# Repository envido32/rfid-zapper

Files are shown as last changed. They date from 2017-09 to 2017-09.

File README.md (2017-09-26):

# RFID Zapper

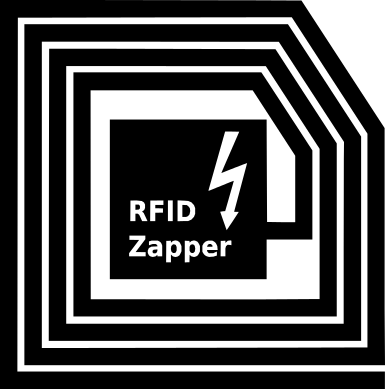
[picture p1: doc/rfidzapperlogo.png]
RFID Zapper


RFID Zapper sirve para quemar, dejando fuera de funcionamiento de forma irreversible los chips tipo RFID como el que se encuentran en llaves de puertas electronicas, [tarjetas de transporte público](https://www.sube.gob.ar/), [pasaportes](https://www.digitalcourage.de/), [boletas de voto electrónico](https://youtu.be/bJT6KLP6tWA), etc. No deja marca visible en absoluto ni emite ruido alguno. 

Este dispositivo debe utilizarse SOLO con fines didácticos o de pruebas. El mal uso del mismo **puede ocasionar serios daños en dispositivos electrónicos.**

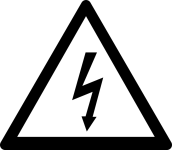
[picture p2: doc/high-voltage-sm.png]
Alto Voltaje


**ATENCIÓN! Este dispositivo tiene una salida en ALTO VOLTAJE. Puede ocasionar daños en el organismo o incluso la muerte si se aplica la descarga sobre el cuerpo. Debe manipularse adecuadamente. No utilizar sin protección adecuada.**

## Licencia

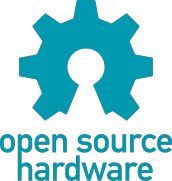
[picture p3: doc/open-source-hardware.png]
Open Source Hardware
 

RFID Zapper es un proyecto libre realizado por [*Manolo Envido*](https://twitter.com/Envido32), basado en el diseño presentado en la serie de videos de [*The Post Apocalyptic Inventor*](https://www.youtube.com/watch?v=E_Nsf0uU8IY&list=PLxaGnte1Dq0my2dtPL5y8sPR7xYXRrOCb).

Libre para utilizar, modificar, compartir y demás bajo los términos de la licencia [CERN Open Hardware Licence v1.2](LICENSE).

## Principio de funcionamiento

Se trata de un circuito elevador de tensión alimentado por una batería alcalina de 9v. Este elevador carga el capacitor y luego al cerrar el segundo interruptor se descarga el capacitor a través de la antena RFID. Esto genera un pulso electromagnético que al ser captado por un chip RFID lo utilizara como alimentación. Al ser un pulso de alta intensidad (y corta duración) la energía absorbida por el chip sera más alta que la soportada por el integrado probocándole un daño irreparable de forma totalmente silenciosa e invisible.

El circuito elevador de tensión es del tipo [boost](https://en.wikipedia.org/wiki/Boost_converter) alimentado por una [batería alcalina de 9v](https://en.wikipedia.org/wiki/Nine-volt_battery). Este circuito es controlado por un [PWM](https://en.wikipedia.org/wiki/Pulse-width_modulation) básico realizado con el [Timer 555](https://en.wikipedia.org/wiki/555_timer_IC) y controlado por el potenciómetro, se recomienda evitar un ciclo de trabajo del PWM mayor al 50% para evitar daños a la batería. Una vez cargado el capacitor el circuito de feedback enciende el LED y desactiva el Timer 555.

## Lite Edition

Menos componentes, más compacto. 

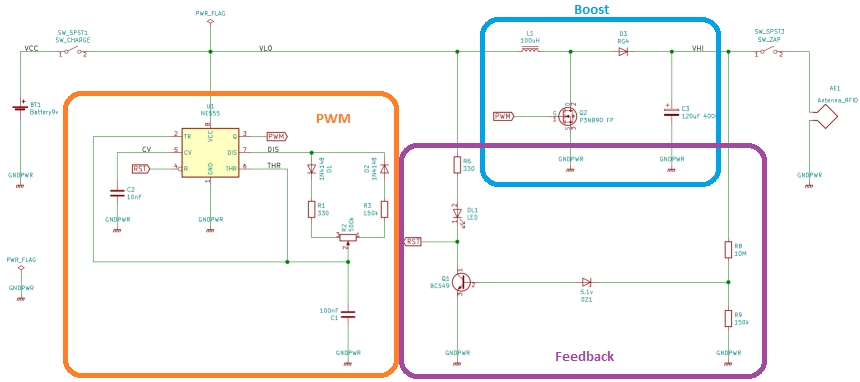
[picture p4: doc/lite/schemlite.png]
Esquema eléctrico


***Made with KiCAD***

Made with KiCAD (http://kicad-pcb.org/)

***Order in PCBWay***

Order in PCBWay (https://www.pcbway.com/project/shareproject/RFID_Zapper.html)

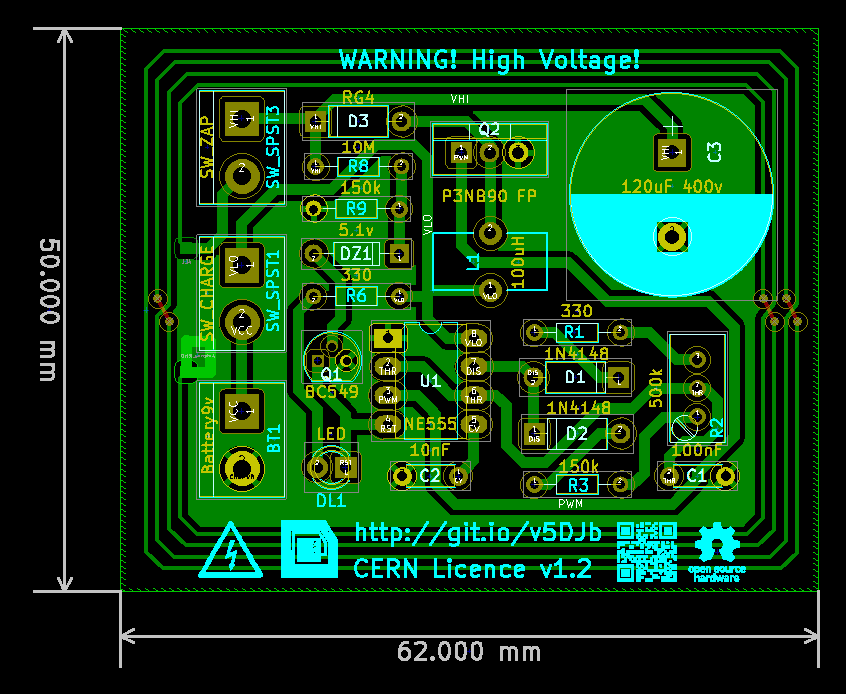
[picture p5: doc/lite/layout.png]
PCB


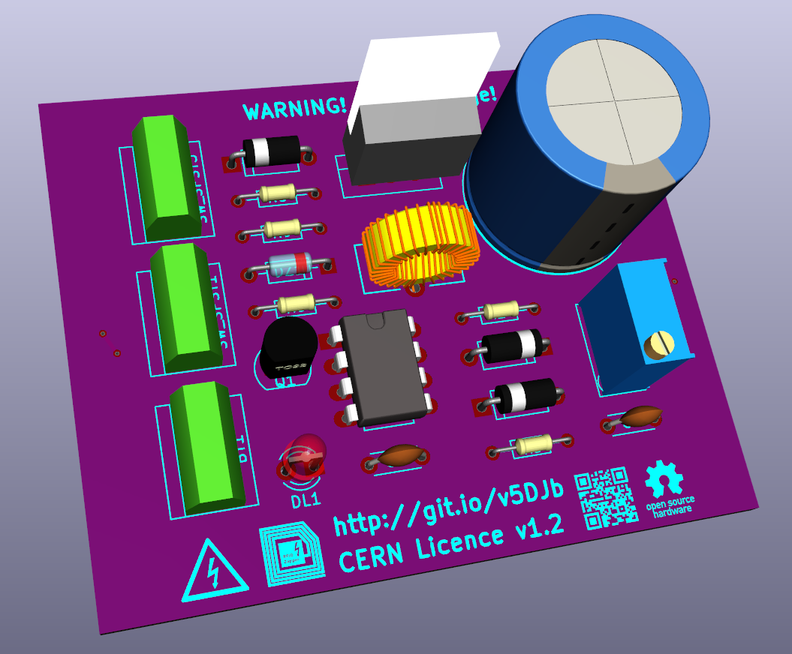
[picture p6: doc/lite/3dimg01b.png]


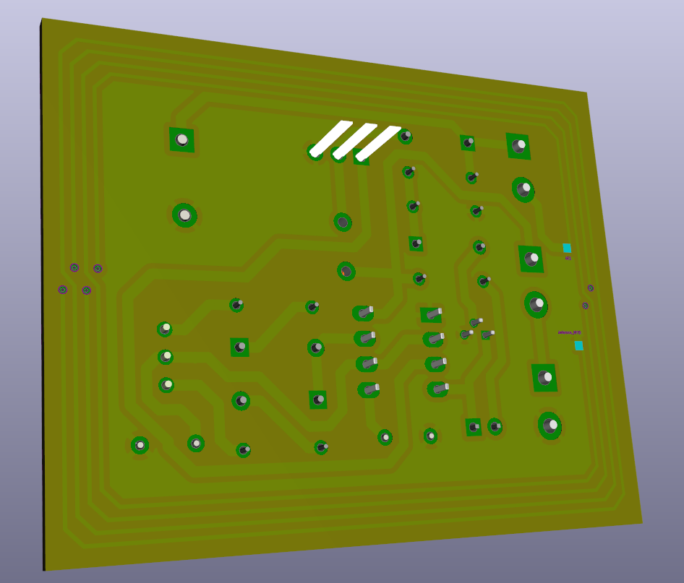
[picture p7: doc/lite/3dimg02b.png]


## Lista de materiales

Description | Part | References | Value | Footprint | Quantity Per PCB
---- | ---- | ---- | ---- | ---- | ---- 
Bornier | 2x1 | SW_SPST1 SW_SPST2 BT1 | SW_CHARGE SW_ZAP Baterry9v | Bornier | 3
Switch | DPDT | SW_SPST1 SW_SPST2 | SW_CHARGE SW_ZAP | Bornier | 1
Battery Cell | Baterry9v | BT1 | Alkaline 9v | Bornier | 1
Timer 555 IC | NE555 | U1 | NE555 | DIP 8 W7.62mm | 1
Capacitor | Ceramic | C1 | 100nF | Disc 4.3mm W1.9mm P5.00mm | 1
Capacitor | Ceramic | C2 | 10nF | Disc 4.3mm W1.9mm P5.00mm | 1
Capacitor | Polarised | C3 | 120uF 400v | Radial D18.0mm P7.50mm | 1
LED | Generic | DL1 | Any colour | LED 3.0mm | 1
Diode | Ultra Fast Recovery Rectifier | D3 | RG4 | P10.16mm | 1
Diode | Generic | D1 D2 | 1N4148 | P10.16mm | 2
Diode | Zenner v5.1 | DZ1 | 1N4733A | P10.16mm | 1
PowerMESH MOSFET | N-CHANNEL 900V 4ohm 3.5 A | Q2 | P3NB90 FP IRF3205| TO-220 | 1
Inductor | With Iron Core | L1 | 100uH | Toroid 5x10mm | 1
Small Signal Transistor | NPN 45V Vce 0.1A Ic | Q1 | BC549 | TO-92 | 1
Resistor | Generic | R1 R6 | 330ohm 1/8w | L3.6mm D1.6mm P7.62mm | 2
Resistor | Generic | R3 R9 | 150kohm 1/8w | L3.6mm D1.6mm P7.62mm | 2
Resistor | Generic | R8 | 10Mohm 1/8w | L3.6mm D1.6mm P7.62mm | 1
Potentionmeter | Trimmer | R2 | 500kohm 1/8w | POT | 1

Costo de los materiales total aproximado (a Septiembre 2017, argentina): 
*10 U$D*

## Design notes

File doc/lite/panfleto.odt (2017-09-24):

PCB visualización

[1] https://www.sube.gob.ar/

[2] https://www.digitalcourage.de/

[3] https://noalvotoelectronico.com/

[4] https://twitter.com/Envido32

[5] https://youtu.be/E_Nsf0uU8IY

[6] https://www.ohwr.org/documents/294

[7] https://en.wikipedia.org/wiki/Boost_converter

[8] https://en.wikipedia.org/wiki/Nine-volt_battery

[9] https://en.wikipedia.org/wiki/Pulse-width_modulation

[10] https://en.wikipedia.org/wiki/555_timer_IC

¡A (https://github.com/envido32/rfid-zapper/blob/master/doc/high-voltage-sm.png)TENCIÓN!

Este dispositivo tiene una salida en ALTO VOLTAJE. Puede ocasionar daños en el organismo o incluso la muerte si se aplica la descarga sobre el cuerpo. Debe manipularse adecuadamente. No utilizar sin protección adecuada.

# RFID Zapper

RFID Zapper

RFID Zapper sirve para quemar, dejando fuera de funcionamiento de forma irreversible los chips tipo RFID como el que se encuentran en llaves de puertas electrónicas, tarjetas de transporte público (https://www.sube.gob.ar/) [1], pasaportes (https://www.digitalcourage.de/) [2], boletas de voto electrónico (https://youtu.be/bJT6KLP6tWA) [3], etc. No deja marca visible en absoluto ni emite ruido alguno.

Este dispositivo debe utilizarse SOLO con fines didácticos o de pruebas. El mal uso del mismo puede ocasionar serios daños en dispositivos electrónicos.

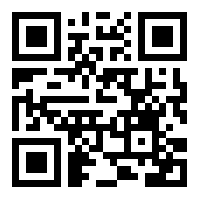
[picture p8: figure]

http://git.io/v5DJb

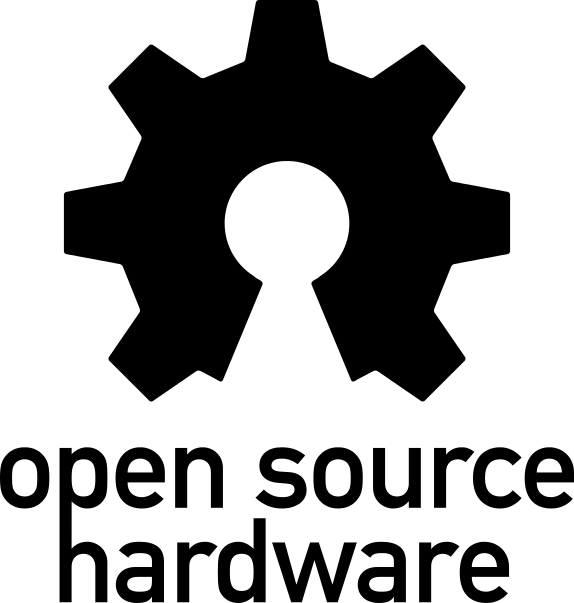
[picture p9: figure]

Licencia

RFID Zapper es un proyecto libre realizado por Manolo Envido (https://twitter.com/Envido32) [4], basado en el diseño presentado en la serie de videos de The Post Apocalyptic Inventor (https://www.youtube.com/watch?v=E_Nsf0uU8IY&list=PLxaGnte1Dq0my2dtPL5y8sPR7xYXRrOCb) [5].

Libre para utilizar, modificar, compartir y demás bajo los términos de la licencia CERN Open Hardware Licence v1.2 (https://github.com/envido32/rfid-zapper/blob/master/LICENSE) [6].

## Principio de funcionamiento

Se trata de un circuito elevador de tensión alimentado por una batería alcalina de 9v. Este elevador carga el capacitor y luego al cerrar el segundo interruptor se descarga el capacitor a través de la antena RFID. Esto genera un pulso electromagnético que al ser captado por un chip RFID lo utilizara como alimentación. Al ser un pulso de alta intensidad (y corta duración) la energía absorbida por el chip sera más alta que la soportada por el integrado probocándole un daño irreparable de forma totalmente silenciosa e invisible.

Esquema eléctrico

(https://github.com/envido32/rfid-zapper/blob/master/doc/lite/schemlite.png)

El circuito elevador de tensión es del tipo boost (https://en.wikipedia.org/wiki/Boost_converter) [7] alimentado por una batería alcalina de 9v (https://en.wikipedia.org/wiki/Nine-volt_battery) [8]. Este circuito es controlado por un PWM (https://en.wikipedia.org/wiki/Pulse-width_modulation) [9] básico realizado con el Timer 555 (https://en.wikipedia.org/wiki/555_timer_IC) [10] y controlado por el potenciómetro, se recomienda evitar un ciclo de trabajo del PWM mayor al 50% para evitar daños a la batería. Una vez cargado el capacitor el circuito de feedback enciende el LED y desactiva el Timer 555.

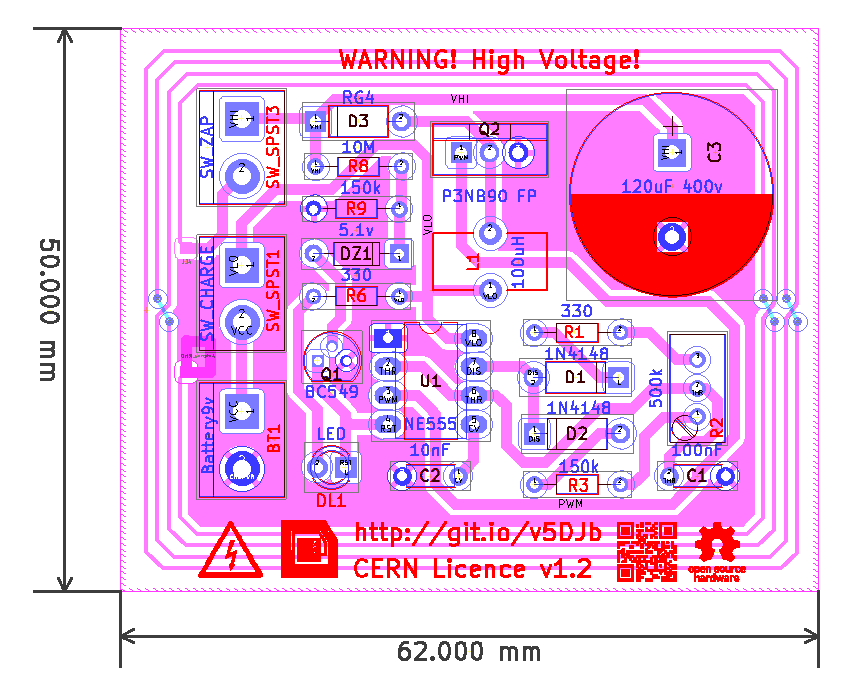
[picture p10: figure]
PCB

(https://github.com/envido32/rfid-zapper/blob/master/doc/lite/layout.png)

## Lista de materiales

Description | Part | References | Value | Footprint | Quantity Per PCB
Bornier | 2x1 | SW_SPST1 SW_SPST2 BT1 | SW_CHARGE SW_ZAP Baterry9v | Bornier | 3
Switch | DPDT | SW_SPST1 SW_SPST2 | SW_CHARGE SW_ZAP | Bornier | 1
Battery Cell | Baterry9v | BT1 | Alkaline 9v | Bornier | 1
Timer 555 IC | NE555 | U1 | NE555 | DIP 8 W7.62mm | 1
Capacitor | Ceramic | C1 | 100nF | Disc 4.3mm W1.9mm P5.00mm | 1
Capacitor | Ceramic | C2 | 10nF | Disc 4.3mm W1.9mm P5.00mm | 1
Capacitor | Polarised | C3 | 120uF 400v | Radial D18.0mm P7.50mm | 1
LED | Generic | DL1 | Any colour | LED 3.0mm | 1
Diode | Ultra Fast Recovery Rectifier | D3 | RG4 | P10.16mm | 1
Diode | Generic | D1 D2 | 1N4148 | P10.16mm | 2
Diode | Zenner v5.1 | DZ1 | 1N4733A | P10.16mm | 1
PowerMESH MOSFET | N-CHANNEL 900V 4ohm 3.5 A | Q2 | P3NB90 FP IRF3205 | TO-220 | 1
Inductor | With Iron Core | L1 | 100uH | Toroid 5x10mm | 1
Small Signal Transistor | NPN 45V Vce 0.1A Ic | Q1 | BC549 | TO-92 | 1
Resistor | Generic | R1 R6 | 330ohm 1/8w | L3.6mm D1.6mm P7.62mm | 2
Resistor | Generic | R3 R9 | 150kohm 1/8w | L3.6mm D1.6mm P7.62mm | 2
Resistor | Generic | R8 | 10Mohm 1/8w | L3.6mm D1.6mm P7.62mm | 1
Potentionmeter | Trimmer | R2 | 500kohm 1/8w | POT | 1

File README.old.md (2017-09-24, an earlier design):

# RFID Zapper

RFID Zapper

RFID Zapper sirve para quemar, dejando fuera de funcionamiento de forma irreversible los chips tipo RFID como el que se encuentran en llaves de puertas electronicas, [tarjetas de transporte público](https://www.sube.gob.ar/), [pasaportes](https://www.digitalcourage.de/), [boletas de voto electrónico](https://youtu.be/bJT6KLP6tWA), etc. No deja marca visible en absoluto ni emite ruido alguno. 

Este dispositivo debe utilizarse SOLO con fines didácticos o de pruebas. El mal uso del mismo **puede ocasionar serios daños en dispositivos electrónicos.**

Alto Voltaje

**ATENCIÓN! Este dispositivo tiene una salida en ALTO VOLTAJE. Puede ocasionar daños en el organismo o incluso la muerte si se aplica la descarga sobre el cuerpo. Debe manipularse adecuadamente. No utilizar sin protección adecuada.**

## Licencia

Open Source Hardware

RFID Zapper es un proyecto libre realizado por [*Manolo Envido*](https://twitter.com/Envido32), basado en el diseño presentado en la serie de videos de [*The Post Apocalyptic Inventor*](https://www.youtube.com/watch?v=E_Nsf0uU8IY&list=PLxaGnte1Dq0my2dtPL5y8sPR7xYXRrOCb)

Libre para utilizar, modificar, compartir y demás bajo los términos de la licencia [CERN Open Hardware Licence v1.2](LICENSE).

## Principio de funcionamiento

Se trata de un circuito elevador de tensión alimentado por una batería alcalina de 9v. Este elevador carga el capacitor y luego al cerrar el segundo interruptor se descarga el capacitor a través de la antena RFID. Esto genera un pulso electromagnético que al ser captado por un chip RFID lo utilizara como alimentación. Al ser un pulso de alta intensidad (y corta duración) la energía absorbida por el chip sera más alta que la soportada por el integrado probocándole un daño irreparable de forma totalmente silenciosa e invisible.

El circuito elevador de tensión es del tipo [boost](https://en.wikipedia.org/wiki/Boost_converter) alimentado por una [batería alcalina de 9v](https://en.wikipedia.org/wiki/Nine-volt_battery). Este circuito es controlado por un [PWM](https://en.wikipedia.org/wiki/Pulse-width_modulation) básico realizado con el [Timer 555](https://en.wikipedia.org/wiki/555_timer_IC) y controlado por el potenciómetro, se recomienda evitar un ciclo de trabajo del PWM mayor al 50% para evitar daños a la batería. Una vez cargado el capacitor el circuito de feedback enciende el LED y desactiva el Timer 555.

## Original Edition

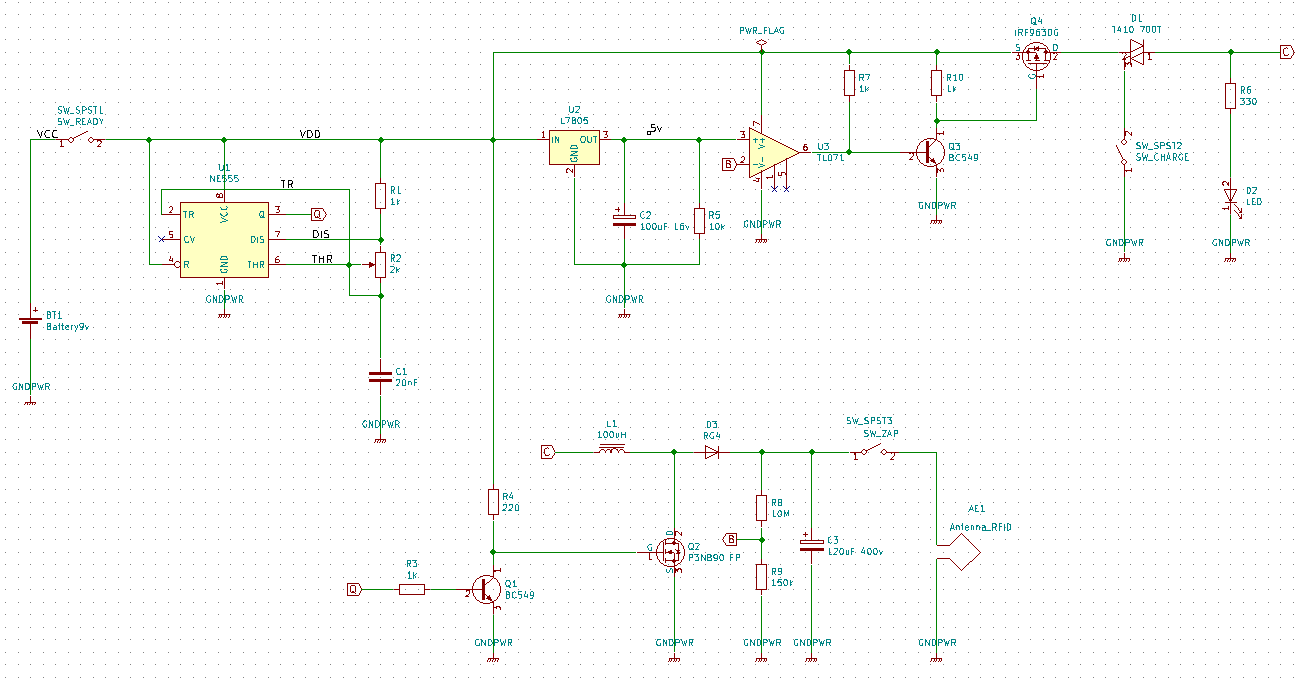
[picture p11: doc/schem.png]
Esquema eléctrico


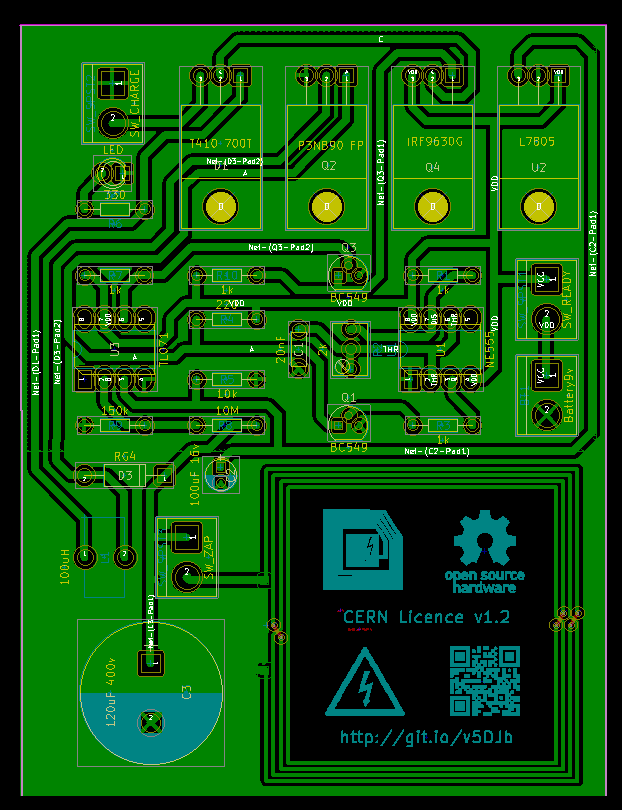
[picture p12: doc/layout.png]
PCB


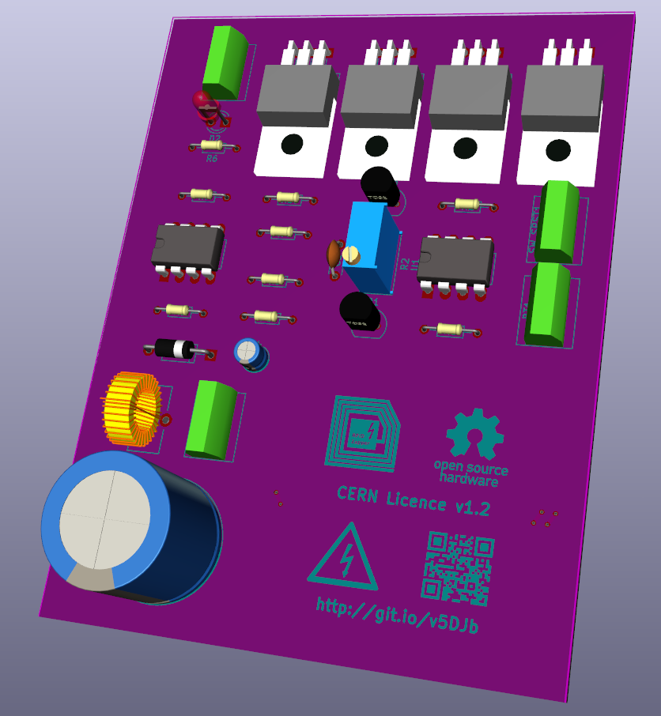
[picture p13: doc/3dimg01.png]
PCB visualización


## Lista de materiales

Description | Part | References | Value | Footprint | Quantity Per PCB
---- | ---- | ---- | ---- | ---- | ---- 
single battery cell | Battery_Cell | BT1 | Battery9v | bornier2 | 1
Polarised capacitor | CP | C2 | 100uF 16v | CP_Radial_D4.0mm_P2.00mm | 1
Polarised capacitor | CP | C3 | 120uF 400v | CP_Radial_D18.0mm_P7.50mm | 1
Unpolarized capacitor | C | C1 | 20nF | C_Disc_D4.3mm_W1.9mm_P5.00mm | 1
LED generic | LED | D2 | LED | LED_D3.0mm | 1
Diode | D | D3 | RG4 | D_A-405_P10.16mm_Horizontal | 1
triode for alternating current (TRIAC) | Q_TRIAC_AAG | D1 | T410 700T | TO-220_Horizontal | 1
Inductor with Iron Core | L_Core_Iron | L1 | 100uH | Choke_Toroid_5x10mm_Vertical | 1
45V Vce, 0.1A Ic, NPN, Small Signal Transistor, TO-92 | BC549 | Q1 Q3 | BC549 | TO-92_Molded_Narrow | 2
6.5A, 200V, 0.800 Ohm, P-Channel Power MOSFET | IRF9540N-RESCUE-RFIDZapper | Q4 | IRF9630G | TO-220_Horizontal | 1
N - CHANNEL 900V - 4 ohm - 3.5 A PowerMESH MOSFET | IRF3205 | Q2 | P3NB90 FP | TO-220_Horizontal | 1
Resistor | R | R8 | 10M | R_Axial_DIN0204_L3.6mm_D1.6mm_P7.62mm_Horizontal | 1
Resistor | R | R5 | 10k | R_Axial_DIN0204_L3.6mm_D1.6mm_P7.62mm_Horizontal | 1
Resistor | R | R9 | 150k | R_Axial_DIN0204_L3.6mm_D1.6mm_P7.62mm_Horizontal | 1
Resistor | R | R1 R3 R7 R10 | 1k | R_Axial_DIN0204_L3.6mm_D1.6mm_P7.62mm_Horizontal | 4
Resistor | R | R4 | 220 | R_Axial_DIN0204_L3.6mm_D1.6mm_P7.62mm_Horizontal | 1
Potentionmeter | POT | R2 | 2k | Potentiometer_Trimmer_Bourns_3266Y | 1
Resistor | R | R6 | 330 | R_Axial_DIN0204_L3.6mm_D1.6mm_P7.62mm_Horizontal | 1
Switch | SW_SPST | SW_SPST2 | SW_CHARGE | bornier2 | 1
Switch | SW_SPST | SW_SPST1 | SW_READY | bornier2 | 1
Switch | SW_SPST | SW_SPST3 | SW_ZAP | bornier2 | 1
5V Voltage regulator | L7805 | U2 | L7805 | TO-220_Horizontal | 1
555-series timer IC | NE555 | U1 | NE555 | DIP-8_W7.62mm_LongPads | 1
Low-Noise JFET-Input Operational Amplifier | TL071-RESCUE-RFIDZapper | U3 | TL071 | DIP-8_W7.62mm_LongPads | 1

Las resistencias son todas de 1/8W o 1/4W. Las llaves/switches y la batería se conectan con borneras o pines. Es recomendable incorporar un pequeño disipador al Q2 (P3NB90).

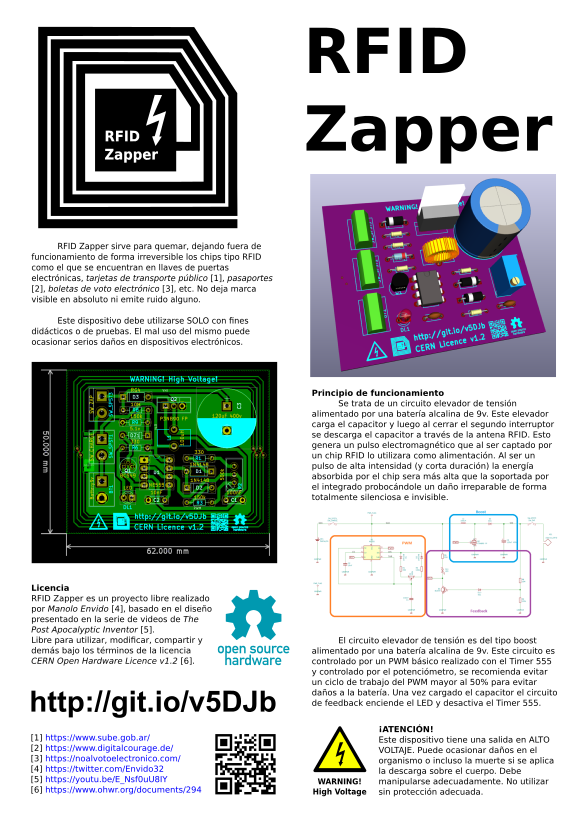
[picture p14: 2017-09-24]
doc/lite/postersm.png

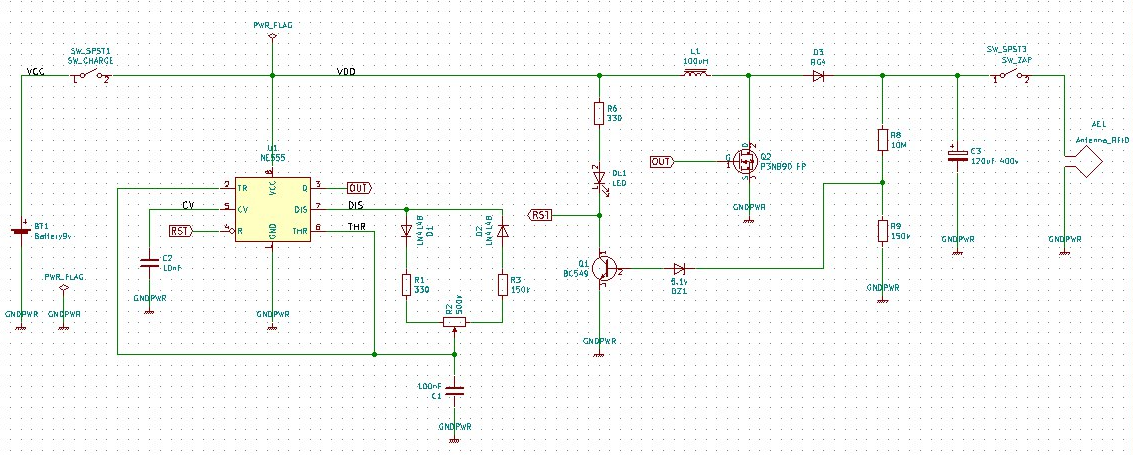
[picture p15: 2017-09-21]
doc/lite/schemlite2.png

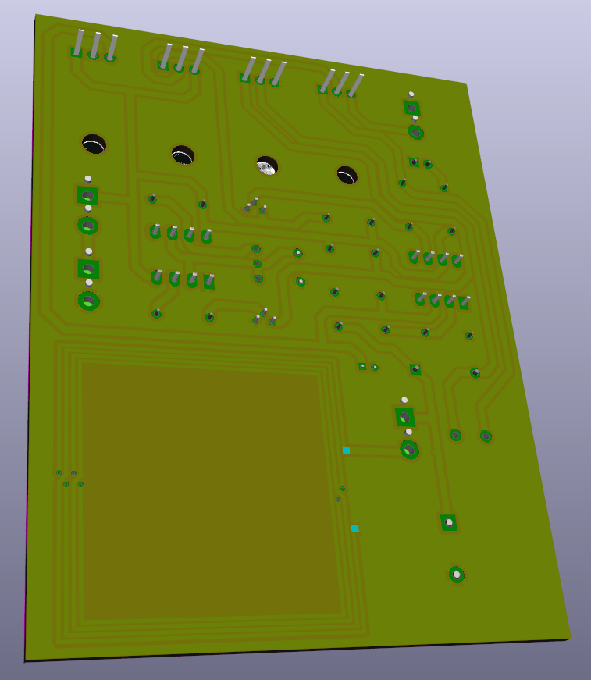
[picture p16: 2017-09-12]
doc/3dimg02.png

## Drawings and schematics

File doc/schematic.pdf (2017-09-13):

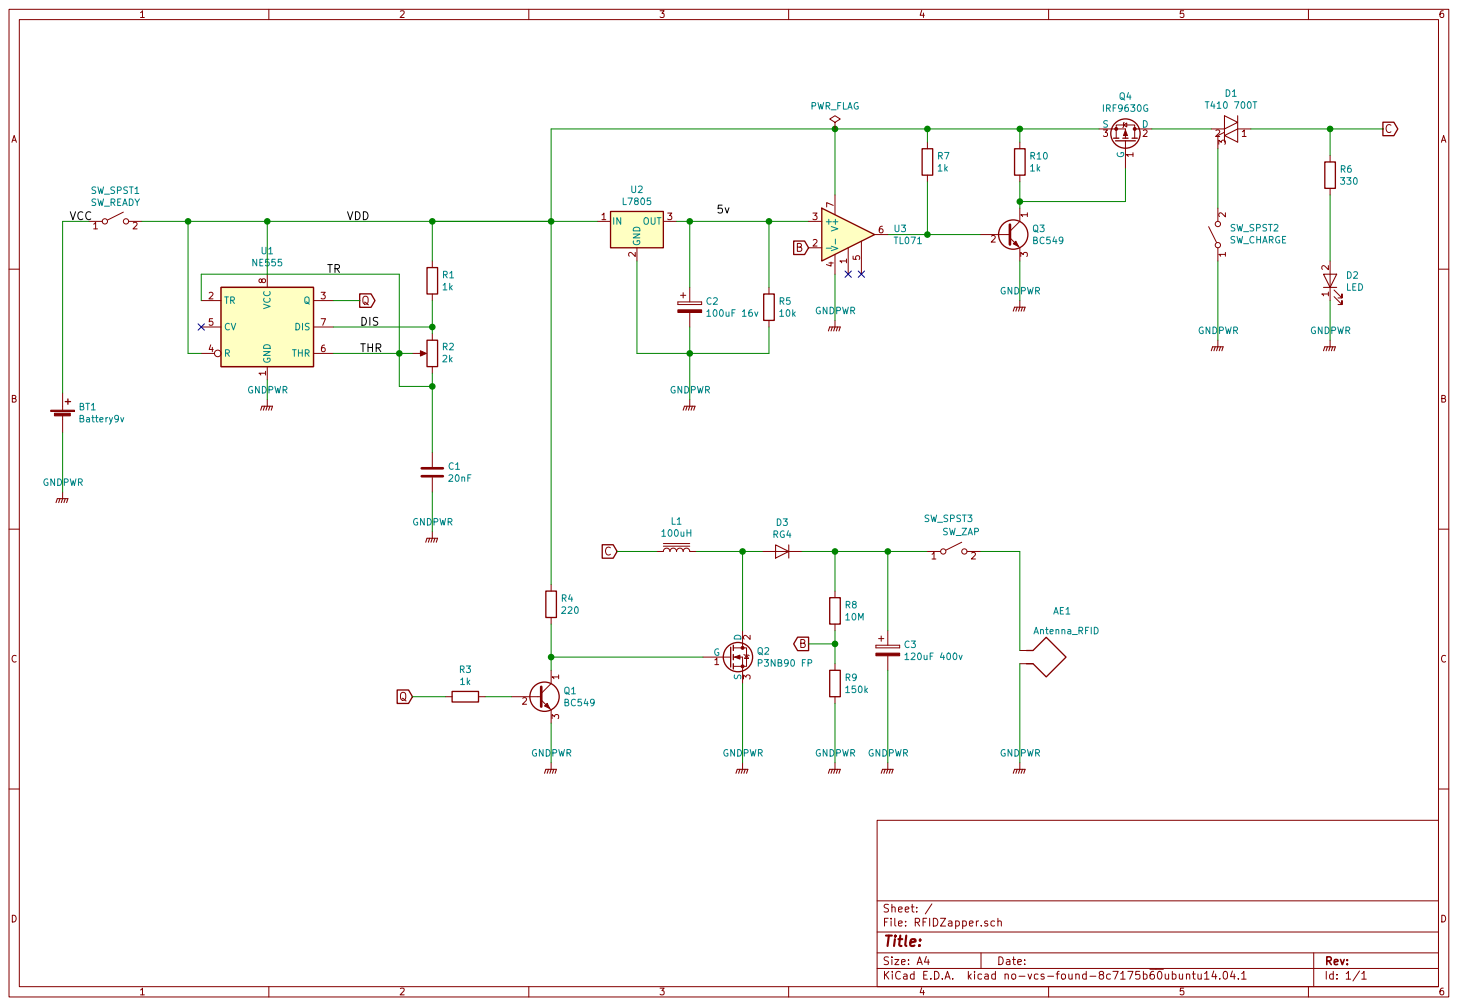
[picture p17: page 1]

3 Q2P3NB90 FP GNDPWR GNDPWR GNDPWR GNDPWR GNDPWR GNDPWR GNDPWR GNDPWR GNDPWR GNDPWR

File: RFIDZapper.sch Sheet: /
Id: 1/1 Title:

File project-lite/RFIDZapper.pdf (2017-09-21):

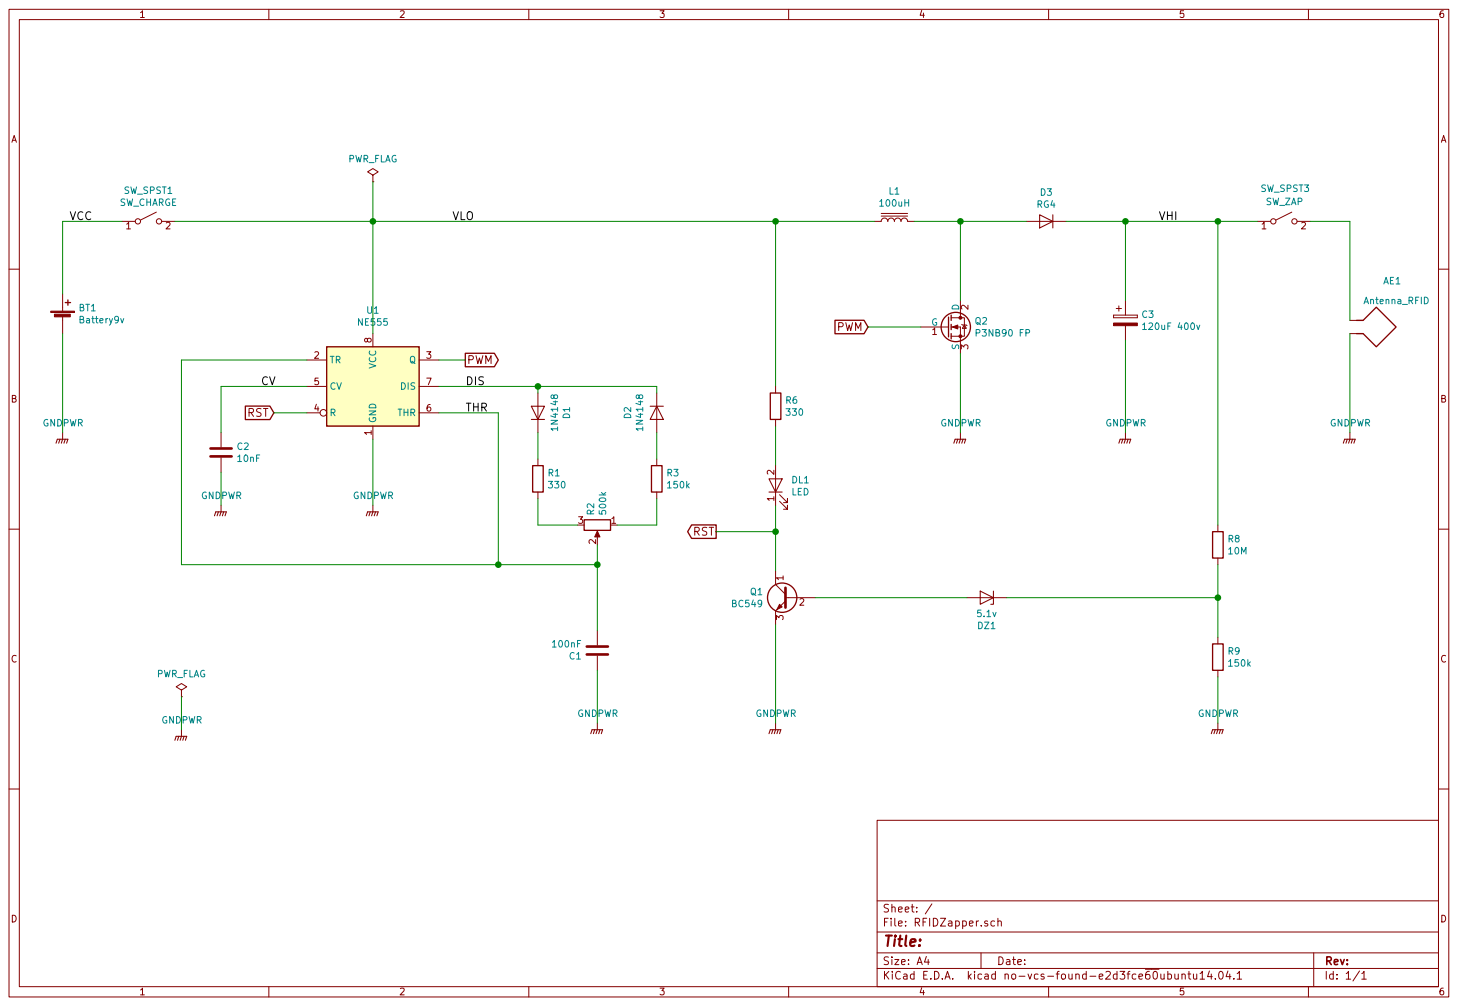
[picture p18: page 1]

3 Q2P3NB90 FP GNDPWR GNDPWR GNDPWR GNDPWR

File: RFIDZapper.sch Sheet: /
Id: 1/1 Title:

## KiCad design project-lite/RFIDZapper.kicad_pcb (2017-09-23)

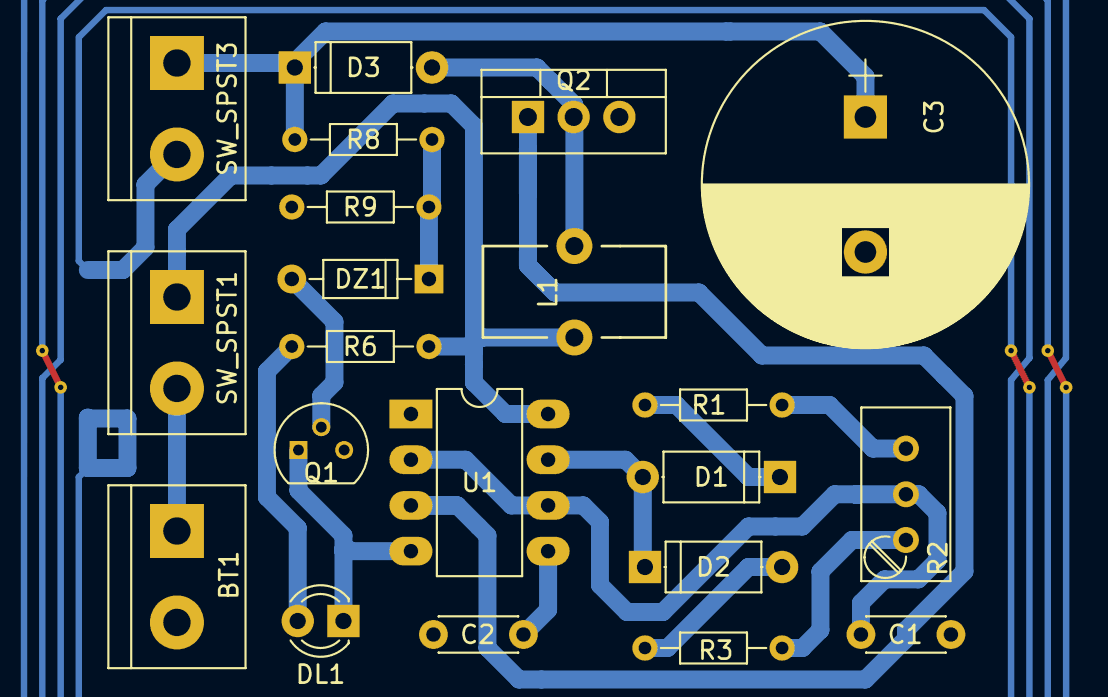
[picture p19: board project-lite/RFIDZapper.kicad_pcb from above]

Board: 2 copper layers, 22 parts (1 on the bottom side), 18 nets.

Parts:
AE1: Antenna_RFID; NFC_ANTENNA2_INSIDE_CONNECTION
BT1: Battery9v; bornier2
C1: 100nF; C_Disc_D4.3mm_W1.9mm_P5.00mm
C2: 10nF; C_Disc_D4.3mm_W1.9mm_P5.00mm
C3: 120uF 400v; CP_Radial_D18.0mm_P7.50mm
D1, D2: 1N4148; D_A-405_P7.62mm_Horizontal
D3: RG4; D_A-405_P7.62mm_Horizontal
DL1: LED; LED_D3.0mm
DZ1: 5.1v; D_DO-35_SOD27_P7.62mm_Horizontal
L1: 100uH; Choke_Toroid_5x10mm_Vertical
Q1: BC549; TO-92_Molded_Narrow
Q2: P3NB90 FP; TO-220_Vertical
R1, R6: 330; R_Axial_DIN0204_L3.6mm_D1.6mm_P7.62mm_Horizontal
R2: 500k; Potentiometer_Trimmer_Bourns_3296W
R3, R9: 150k; R_Axial_DIN0204_L3.6mm_D1.6mm_P7.62mm_Horizontal
R8: 10M; R_Axial_DIN0204_L3.6mm_D1.6mm_P7.62mm_Horizontal
SW_SPST1: SW_CHARGE; bornier2
SW_SPST3: SW_ZAP; bornier2
U1: NE555; DIP-8_W7.62mm_LongPads

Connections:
/CV: C2.1, U1.5
/DIS: D1.2, D2.1, U1.7
/THR: C1.2, R2.2, U1.2, U1.6
/VCC: BT1.1, SW_SPST1.2
/VHI: C3.1, D3.1, R8.1, SW_SPST3.1
/VLO: L1.1, R6.1, SW_SPST1.1, U1.8
GNDPWR: AE1.2, BT1.2, C1.1, C2.2, C3.2, Q1.3, Q2.3, R9.2, U1.1
unnamed: AE1.1, SW_SPST3.2
unnamed: D1.1, R1.1
unnamed: D2.2, R3.1
unnamed: D3.2, L1.2, Q2.2
unnamed: DL1.2, R6.2
unnamed: DZ1.1, R8.2, R9.1
unnamed: DZ1.2, Q1.2
unnamed: R1.2, R2.3
unnamed: R2.1, R3.2
PWM: Q2.1, U1.3
RST: DL1.1, Q1.1, U1.4

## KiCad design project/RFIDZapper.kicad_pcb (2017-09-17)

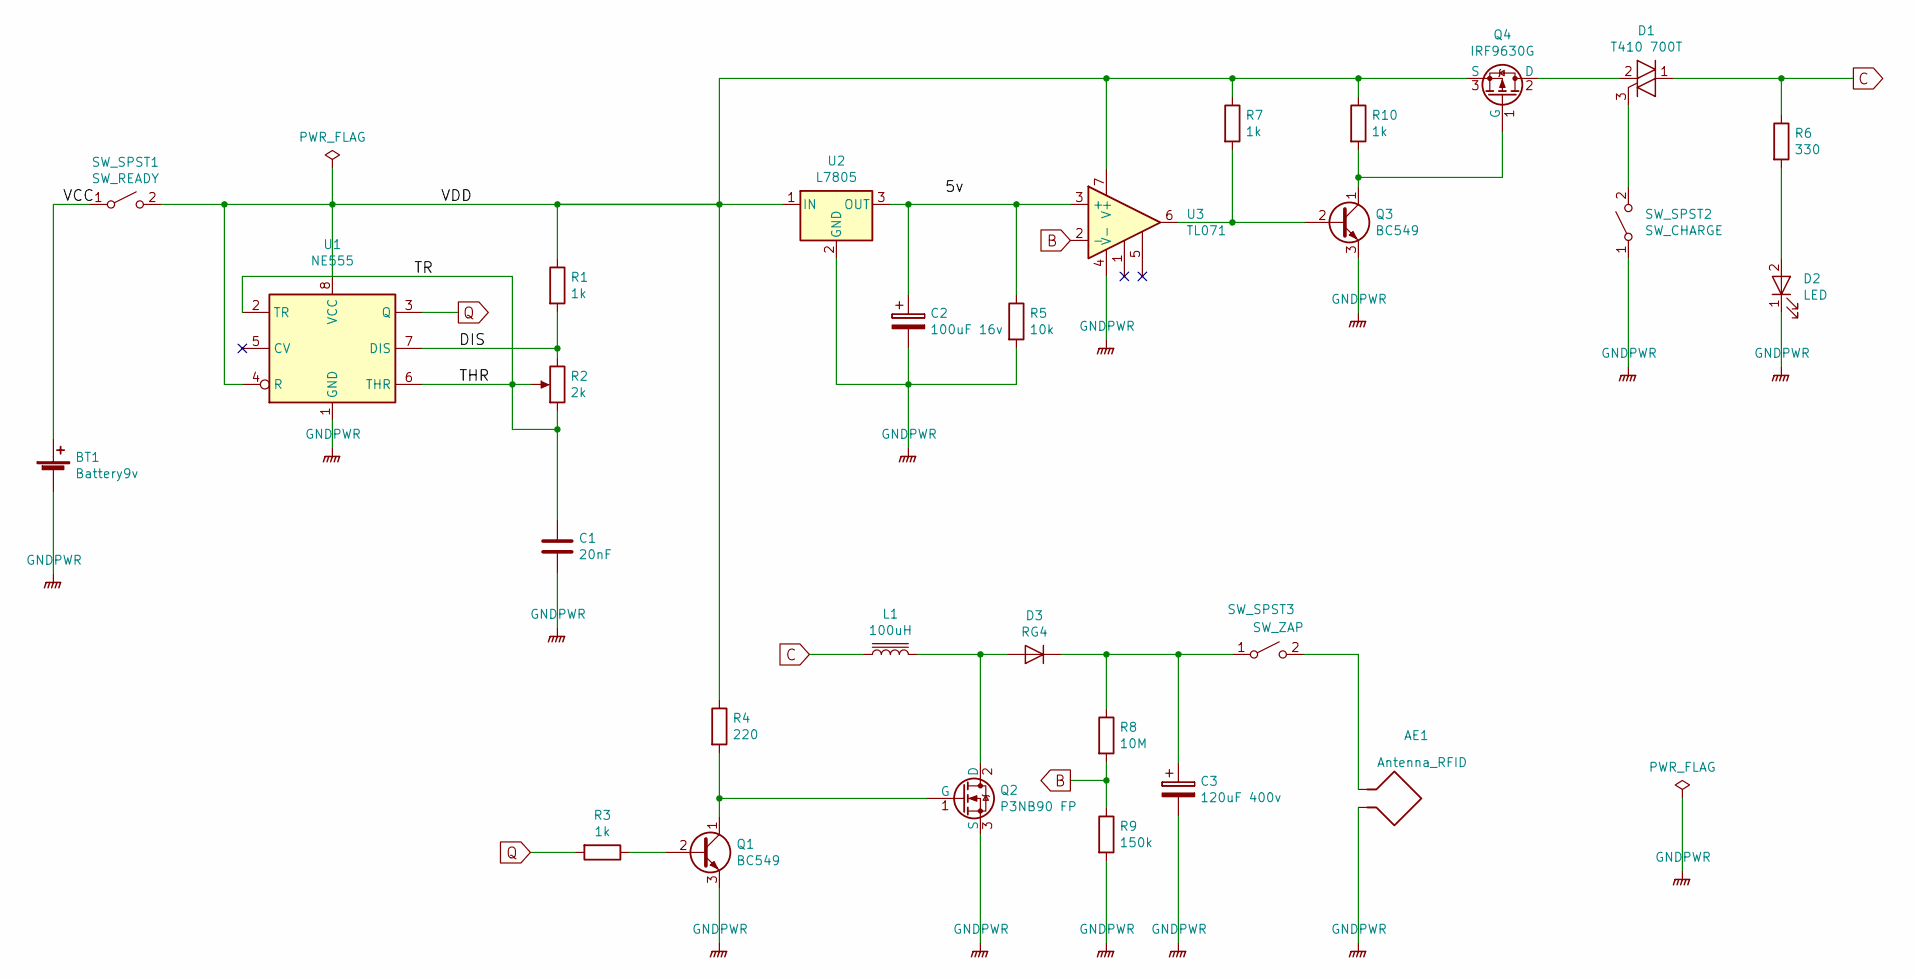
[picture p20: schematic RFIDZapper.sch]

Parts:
AE1: Antenna_RFID; NFC_ANTENNA_40_40
BT1: Battery9v; bornier2
C1: 20nF; C_Disc_D4.3mm_W1.9mm_P5.00mm
C2: 100uF 16v; CP_Radial_D4.0mm_P2.00mm
C3: 120uF 400v; CP_Radial_D18.0mm_P7.50mm
D1: T410 700T; TO-220_Horizontal
D2: LED; LED_D3.0mm
D3: RG4; D_A-405_P10.16mm_Horizontal
L1: 100uH; Choke_Toroid_5x10mm_Vertical
Q1, Q3: BC549; TO-92_Molded_Narrow
Q2: P3NB90 FP; TO-220_Horizontal
Q4: IRF9630G; TO-220_Horizontal
R1, R3, R7, R10: 1k; R_Axial_DIN0204_L3.6mm_D1.6mm_P7.62mm_Horizontal
R2: 2k; Potentiometer_Trimmer_Bourns_3296W
R4: 220; R_Axial_DIN0204_L3.6mm_D1.6mm_P7.62mm_Horizontal
R5: 10k; R_Axial_DIN0204_L3.6mm_D1.6mm_P7.62mm_Horizontal
R6: 330; R_Axial_DIN0204_L3.6mm_D1.6mm_P7.62mm_Horizontal
R8: 10M; R_Axial_DIN0204_L3.6mm_D1.6mm_P7.62mm_Horizontal
R9: 150k; R_Axial_DIN0204_L3.6mm_D1.6mm_P7.62mm_Horizontal
SW_SPST1: SW_READY; bornier2
SW_SPST2: SW_CHARGE; bornier2
SW_SPST3: SW_ZAP; bornier2
U1: NE555; DIP-8_W7.62mm_LongPads
U2: L7805; TO-220_Horizontal
U3: TL071; DIP-8_W7.62mm_LongPads

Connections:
/DIS: R1.2, R2.3, U1.7 (DIS)
/THR: C1.1, R2.1, R2.2, U1.2 (TR), U1.6 (THR)
/VCC: BT1.1 (+), SW_SPST1.1 (A)
/VDD: Q4.3 (S), R1.1, R4.1, R7.1, R10.1, SW_SPST1.2 (B), U1.4 (R), U1.8 (VCC), U2.1 (IN), U3.7 (V+)
A: Q1.1 (C), Q2.1 (G), R4.2
B: R8.2, R9.1, U3.2 (-)
C: D1.2 (A2), Q4.2 (D)
GNDPWR: AE1.2, BT1.2 (-), C1.2, C2.2, C3.2, D2.1 (K), Q1.3 (E), Q2.3 (S), Q3.3 (E), R5.2, R9.2, SW_SPST2.1 (A), U1.1 (GND), U2.2 (GND), U3.4 (V-)
unnamed: AE1.1, SW_SPST3.2 (B)
unnamed: C2.1, R5.1, U2.3 (OUT), U3.3 (+)
unnamed: C3.1, D3.1 (K), R8.1, SW_SPST3.1 (A)
unnamed: D1.1 (A1), L1.1, R6.1
unnamed: D1.3 (G), SW_SPST2.2 (B)
unnamed: D2.2 (A), R6.2
unnamed: D3.2 (A), L1.2, Q2.2 (D)
unnamed: Q1.2 (B), R3.1
unnamed: Q3.1 (C), Q4.1 (G), R10.2
unnamed: Q3.2 (B), R7.2, U3.6
Q: R3.2, U1.3 (Q)

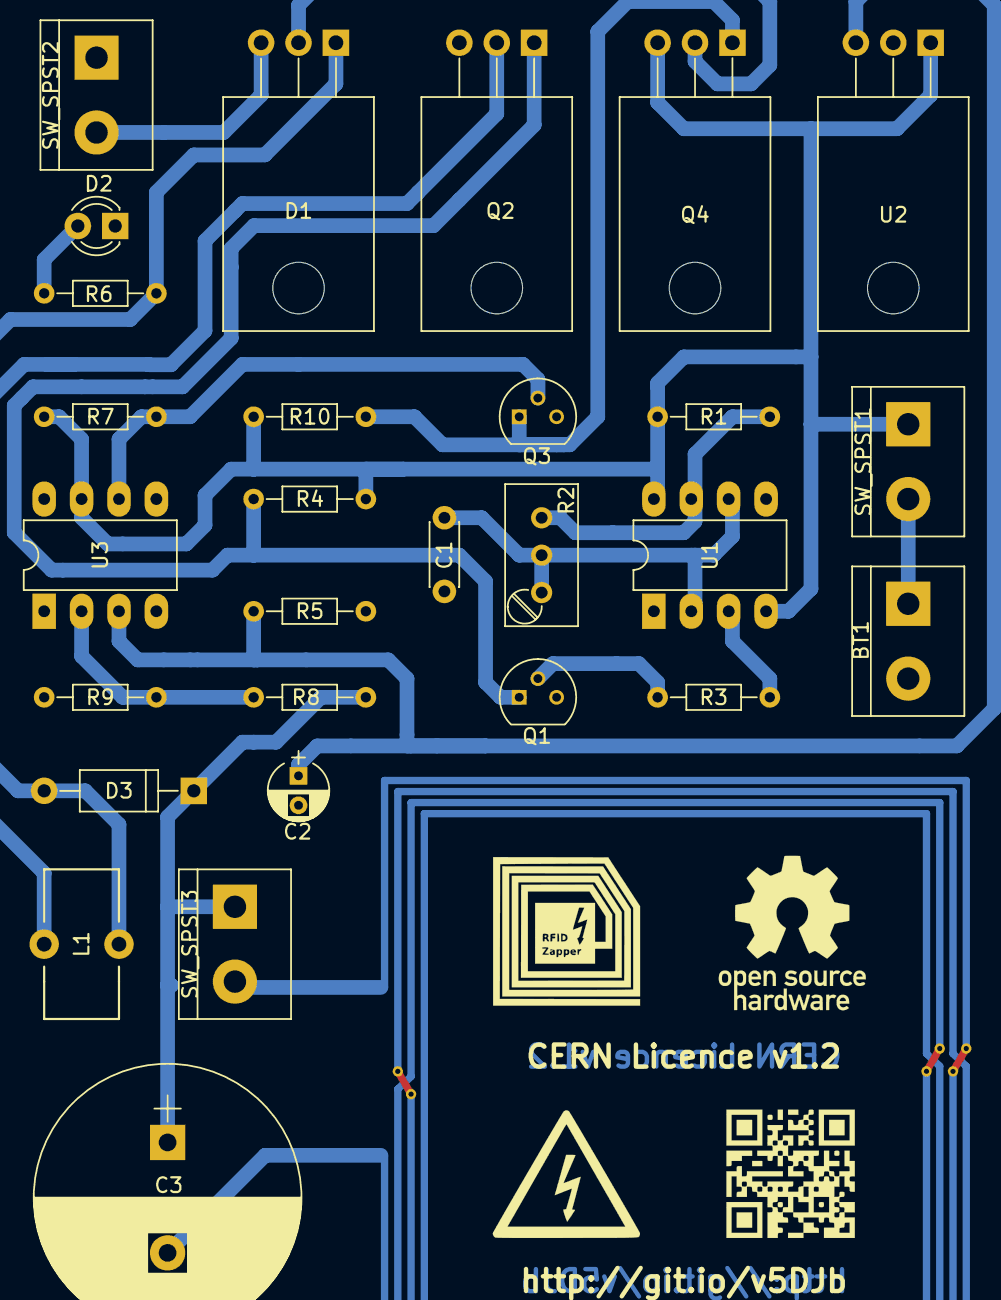
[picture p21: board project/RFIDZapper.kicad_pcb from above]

Board: 2 copper layers, 29 parts (1 on the bottom side), 19 nets.

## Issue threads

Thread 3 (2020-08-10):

Necesito ayuda con el D3

hnrIT, 2020-08-10:
Hola a todos.

Estoy intentando construír el proyecto y tengo dudas; mis conocimientos de electrónica son muy, muy básicos. Cuando voy a comprar los componentes me piden más información del diodo D3, valores en voltios y amperios. ¿Alguien me puede echar una mano al respecto?

Gracias y saludos.

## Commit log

2017-09-12 Add details to README
    Reorder project files.
    [RFIDZapper.kicad_pcb, RFIDZapper.sch]
2017-09-13 Added logos
    [RFIDZapper.kicad_pcb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]
2017-09-14 Better 3D
    [RFIDZapper.kicad_pcb, RFIDZapper.sch]
2017-09-17 Lite edition
    [RFIDZapper.kicad_pcb, RFIDZapper.sch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]
2017-09-17 Lite routed
    [RFIDZapper.kicad_pcb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]
2017-09-17 Minor logos update
    [RFIDZapper-B.Cu.gbr, RFIDZapper-B.Mask.gbr, RFIDZapper-B.SilkS.gbr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]
2017-09-21 New Lite
    [RFIDZapper-B.Cu.gbr, RFIDZapper-B.Mask.gbr, RFIDZapper-B.SilkS.gbr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]
2017-09-21 Cap rotated
    [RFIDZapper-B.Cu.gbr, RFIDZapper-B.Mask.gbr, RFIDZapper-B.SilkS.gbr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]
2017-09-21 Agragados los principios de funcionamiento
2017-09-21 Minor fixes
    [RFIDZapper-B.Cu.gbl, RFIDZapper-B.Mask.gbs, RFIDZapper-B.SilkS.gbo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]
2017-09-23 Gerber RS-247x with gerbV
    [RFIDZapper-B.Cu.gbl, RFIDZapper-B.Mask.gbs, RFIDZapper-B.Paste.gbp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]
2017-09-23 Added Bill of Materials
2017-09-23 PCBWay link
2017-09-24 Added KiCAD logo
2017-09-24 Made with KiCAD
